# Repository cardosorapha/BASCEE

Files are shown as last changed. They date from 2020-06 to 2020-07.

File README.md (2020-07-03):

# BASCEE

Este é um projeto de clone de Arduino utilizando o ATMega328P com duas memórias EEPROM e Calendário. O módulo disponibiliza saídas digitais, portas de comunicação I2C e serial, além de pinos para programação do microcontrolador. 

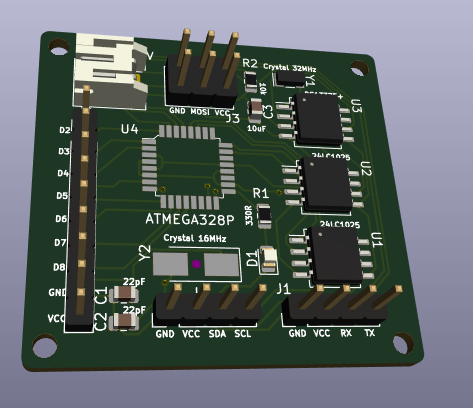
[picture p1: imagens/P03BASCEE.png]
Frente


## Conexões

TODO: Colocar imagem do esquemático com breve descrição.

## Arquivos

O design principal, contido em "P03BASCEE.kicad_pcb" é de duas camadas com um plano de terra na camada inferior de cobre. Os arquivos "P03BASCEE_2Layers.kicad_pcb" e "P03BASCEE_4Layers.kicad_pcb" representam versões recém roteadas para duas e quatro camadas.

O arquivo "P03BASCEE.sch" contém o esquemático principal com uma página hierárquica, definida em "Connectors.sch", que contém os conectores do projeto.

Os esquemáticos de componentes utilizados no projeto estão contidos em "P03BASCEE-cache.lib", que pode ser carregado em qualquer instância de KiCAD sem que hajam esquemáticos nas bibliotecas globais ([como instalar bibliotecas não oficiais](https://kicad-pcb.org/libraries/third_party/)).

Os footprints de componentes utilizados no projeto estão contidos em "P03BASCEE.pretty", que pode ser carregado em qualquer instância de KiCAD sem que hajam footprints nas bibliotecas globais ([como instalar bibliotecas não oficiais](https://kicad-pcb.org/libraries/third_party/)).

## Roteamento

O roteamento dessa placa foi automático utilizando o [FreeRouting](https://freerouting.org/), que recebe arquivos exportados do KiCAD e realiza roteamentos minimizando o tamanho das camadas.

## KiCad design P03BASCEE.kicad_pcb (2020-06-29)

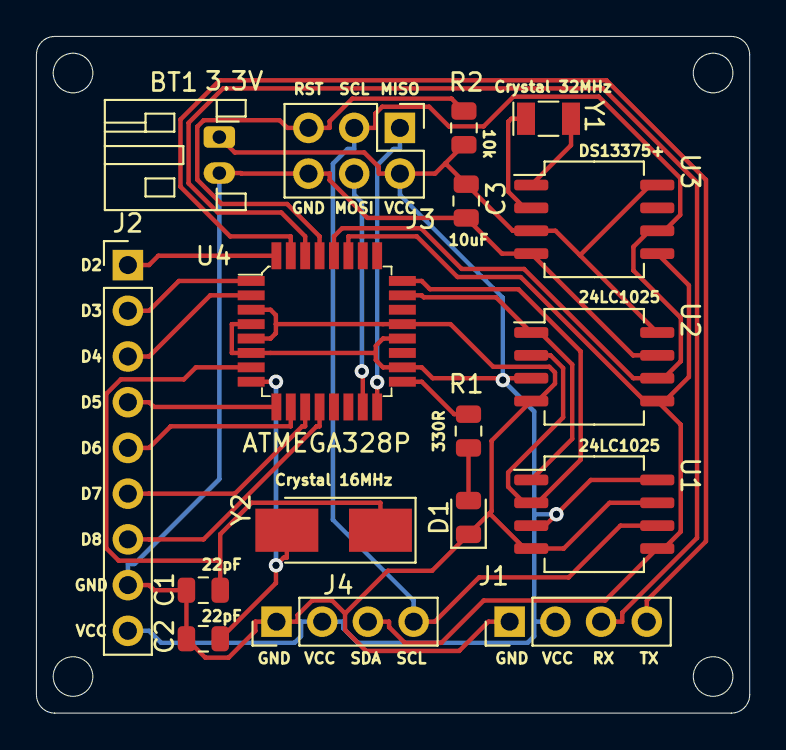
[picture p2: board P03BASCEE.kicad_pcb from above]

Board: 2 copper layers, 39.6 x 37.6 mm, 21 parts (0 on the bottom side), 24 nets.

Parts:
BT1: Battery 3V; JST_PH_S2B-PH-K_1x02_P2.00mm_Horizontal
C1, C2: 22pF; C_0805_2012Metric
C3: 10uF; C_0805_2012Metric
D1: LED; LED_0805_2012Metric
H1, H2, H3, H4: MountingHole; MountingHole_2.2mm_M2_DIN965
J1: Serial; PinHeader_1x04_P2.54mm_Vertical
J2: Digital; PinHeader_1x09_P2.54mm_Vertical
J3: ICSP; PinHeader_2x03_P2.54mm_Vertical
J4: I2C; PinHeader_1x04_P2.54mm_Vertical
R1: 330R; R_0805_2012Metric
R2: 10k; R_0805_2012Metric
U1, U2: 24LC1025; SO-8_5.3x6.2mm_P1.27mm
U3: DS13375+; SO-8_5.3x6.2mm_P1.27mm
U4: ATMEGA328P; TQFP-32_7x7mm
Y1: Crystal 32MHz; Crystal_SMD_MicroCrystal_CC7V-T1A-2Pin_3.2x1.5mm
Y2: Crystal 16MHz; Crystal_SMD_5032-2Pin_5.0x3.2mm_HandSoldering

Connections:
/ADSS1: U1.1, U2.1, U4.23
/ADSS2: U1.2, U2.2, U4.24
/D2: J2.1, U4.32
/D3: J2.2, U4.1
/D4: J2.3, U4.2
/D5: J2.4, U4.9
/D6: J2.5, U4.10
/D7: J2.6, U4.11
/D8: J2.7, U4.12
/MISO: J3.1, U4.16
/MOSI: J3.4, U4.15
/RESET: J3.5, R2.1, U4.29
/RX: J1.3, U4.30
/SCK: J3.3, J4.4, U1.6, U2.6, U3.6, U4.28
/SDA: J4.3, U1.5, U2.5, U3.5, U4.27
/TX: J1.4, U4.31
/VCC: BT1.1, C3.1, J1.2, J2.9, J3.2, J4.2, R2.2, U1.3, U1.8, U2.3, U2.8, U3.3, U3.8, U4.4, U4.6, U4.18, U4.20
GND: BT1.2, C1.2, C2.2, C3.2, D1.1, J1.1, J2.8, J3.6, J4.1, U1.4, U1.7, U2.4, U2.7, U3.4, U4.3, U4.5, U4.21
unnamed: C1.1, U4.7, Y2.1
unnamed: C2.1, U4.8, Y2.2
unnamed: D1.2, R1.2
unnamed: R1.1, U4.17
unnamed: U3.1, Y1.2
unnamed: U3.2, Y1.1

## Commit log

2020-06-28 Criação do repositório
    [P03BASCEE.kicad_pcb, P03BASCEE.sch]
2020-06-28 Configuração do bloco de título no esquemático
    [P03BASCEE.sch]
2020-06-28 Adicionados primeiros componentes disponíveis fora de páginas hierárquicas
    [P03BASCEE.sch]
2020-06-28 Criada página hierárquica para conectores
    [Connectors.sch, P03BASCEE.sch]
2020-06-28 Conectores colocados na página hierárquica correspondente
    [Connectors.sch, P03BASCEE.sch]
2020-06-28 Criado novo símbolo para CI e adicionado microcontrolador
    [P03BASCEE.sch]
2020-06-28 Adicionados cristais que faltavam
    [P03BASCEE.sch]
2020-06-28 Símbolos organizados
    [Connectors.sch, P03BASCEE.sch]
2020-06-28 Símbolos anotados
    [Connectors.sch, P03BASCEE.sch]
2020-06-28 Todos os valores e footprints adicionados
    [Connectors.sch, P03BASCEE.sch]
2020-06-28 Ligação dos conectores
    [Connectors.sch, P03BASCEE.sch]
2020-06-29 Feitas ligações entre componentes
    [P03BASCEE.sch]
2020-06-29 Esquemático completado e passou do DRC
    [P03BASCEE.sch]
2020-06-29 Descrições funcionais adicionadas
    [Connectors.sch, P03BASCEE.sch]
2020-06-29 Criado arquivo de PCB e corrigido título do esquemático
    [P03BASCEE.sch]
2020-06-29 Componentes colocados na PCB
    [P03BASCEE.kicad_pcb]
2020-06-29 Furos de parafuso adicionados no esquemático e no PCB (boa prática)
    [P03BASCEE.kicad_pcb, P03BASCEE.sch]
2020-06-29 Componentes ajustados de forma compacta na PCB
    [P03BASCEE.kicad_pcb]
2020-06-29 Criada borda da placa - sem espaço para buracos de montage
    [P03BASCEE.kicad_pcb]
2020-06-29 Criada borda da placa - buracos de montagem reduzidos para 2.2mm e incluídos
    [P03BASCEE.kicad_pcb, P03BASCEE.sch]
2020-06-29 Roteamento concluído para duas camadas
    [P03BASCEE.kicad_pcb]
2020-06-29 Roteamento concluído para duas camadas, adicionando arquivos restantes
    [P03BASCEE.dsn, P03BASCEE_2Layers.kicad_pcb]
2020-06-29 Roteamento para quatro camadas, projeto principal com duas
    [P03BASCEE_2Layer.dsn, P03BASCEE_4Layer.dsn, P03BASCEE_4Layers.kicad_pcb]
2020-06-29 Modificatos silkscreens para projeto duas camadas e adicionadas dimensões
    [P03BASCEE.kicad_pcb]
